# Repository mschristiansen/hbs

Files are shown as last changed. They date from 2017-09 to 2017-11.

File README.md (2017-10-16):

Controller for the Harley Brewing System
========================================

Install Dependencies
--------------------

Requires `avrdude` and `gcc-avr`.

```
$ sudo apt install arduino-mk
```

Initialise git submodules to fetch source code for display and
temperature sensor (installed in `firmware/lib`).

```
$ git submodule init
```

Compile and Upload Firmware
---------------------------

The firmware was tested with Arduino UNO and Arduino Pro Mini. Both of
these boards will auto reset i.e. no need to manually reset before
upload.

Change port and baud rate in `firmware/Makefile` according to
board. The Arduino UNO is generally on port `/dev/ttyACM0` and can
handle speeds up to 115200 baud. The Arduino Pro Mini is generally on
port `/dev/ttyUSB0` and can only handle speeds up to 57600 baud.

```
$ make upload
```

References
----------

- http://www.nongnu.org/avr-libc/user-manual/index.html
- http://playground.arduino.cc/Learning/OneWire

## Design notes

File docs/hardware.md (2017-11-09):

Hardware Setup
==============

Built on Arduino Uno.

DS18B20 Temperature Sensor
--------------------------

- [datasheet](https://cdn.sparkfun.com/datasheets/Sensors/Temp/DS18B20.pdf)
- 5 volt power
- One wire to pin 9 with 4.7k resistor for pull-up
- DS18x20 family

SSD1306 OLED Display
--------------------

- Monochrome
- 128x32 pixels
- 5 volt power
- SDA from display to A4
- SCL from display to A5

Solid-State Relay
-----------------

To control the heater is connected on pin 11, which supports PWM.

MOSFET
------

To control the pump is connected on pin 10. This pin supports PWM, but
that functionality is currently not used.

Buttons
-------

- Button for 'Select' on pin 2 to ground
- Button for 'Next' on pin 3 to ground
- Both pin 2 and 3 support interrupts

Buzzer
------

Buzzer El-Mag PCB 5V, 30 mA attached to pin 8

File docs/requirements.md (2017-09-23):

Requirements
============

1. Must measure the temperature
2. Must display the temperature
3. Must allow setting the temperature
4. Must display the setpoint temperature
5. Must allow switching the pump on and off
6. Must display pump status (on/off)
7. Must make a sound when setpoint temperature is reached

Specifications
--------------

The system will consist of a temperature probe, two buttons, a
display, a buzzer, a solid state relay for the heater and a MOSFET for
the pump.

State
-----

actualTemp
setTemp

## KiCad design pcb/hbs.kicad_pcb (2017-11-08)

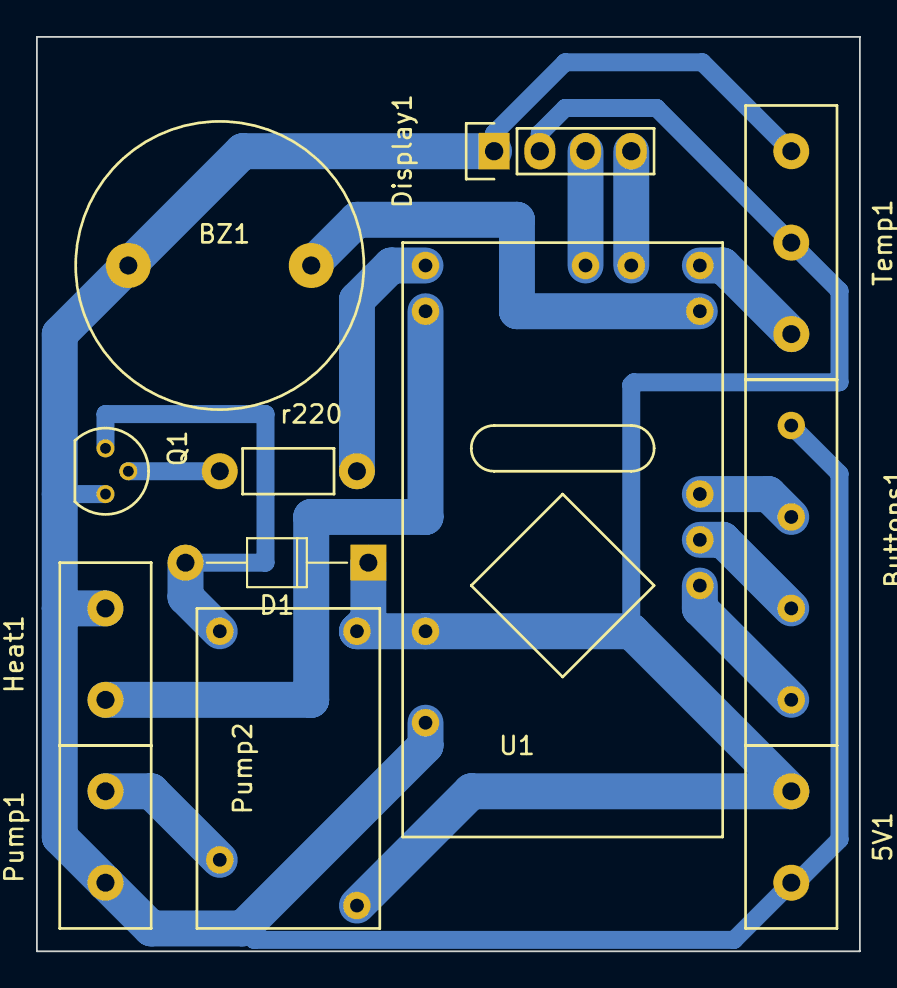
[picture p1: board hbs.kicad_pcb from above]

Board: 2 copper layers, 45.7 x 50.8 mm, 12 parts (0 on the bottom side), 14 nets.

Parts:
5V1: Screw_Terminal_01x02; screw-terminal-2-5.08
BZ1: Buzzer; BUZZER
Buttons1: Conn_01x04; screw-terminal-4-5.08
D1: 1N4148; D_T-1_P10.16mm_Horizontal
Display1: JST Conn; Pin_Header_Straight_1x04
Heat1: Screw_Terminal_01x02; screw-terminal-2-5.08
Pump1: Screw_Terminal_01x02; screw-terminal-2-5.08
Pump2: FINDER-36.11-4301; relay-OJE-SS-105HM
Q1: BC337; TO-92_Molded_Narrow
Temp1: Screw_Terminal_01x03; screw-terminal-3-5.08
U1: RobotDynProMini
r220: R; Resistor_Horizontal_RM7mm

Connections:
GND: 5V1.1, BZ1.1, Buttons1.1, Display1.1, Heat1.1, Pump1.1, Q1.3, Temp1.1, U1.GND
unnamed: BZ1.2, U1.D8
unnamed: Buttons1.2, U1.D4
unnamed: Buttons1.3, U1.D3
unnamed: Buttons1.4, U1.D2
unnamed: D1.2, Pump2.A1, Q1.1
unnamed: Display1.3, U1.A5
unnamed: Display1.4, U1.A4
unnamed: Heat1.2, U1.D11
unnamed: Pump1.2, Pump2.14
unnamed: Q1.2, r220.1
unnamed: Temp1.3, U1.D9
unnamed: U1.D10, r220.2
VCC: 5V1.2, D1.1, Display1.2, Pump2.11, Pump2.A2, Temp1.2, U1.VCC

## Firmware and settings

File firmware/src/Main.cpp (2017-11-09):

#include <Arduino.h>
#include "HBS.h"

void setup();
void loop();

// define the initial state for the system.
struct state initial = {
  0,    // actual temperature
  50,   // setpoint temperature
  OFF,  // Heater
  0,    // Duty-cycle on heater
  OFF,  // Pump
  OFF,  // Buzzer
  HEAT  // Selected menu
};

// Create and initialise the state for the system.
struct state *hbs = &initial;

// Prototypes.
void pumpInit();
void pumpUpdate(int dutyCycle);
void heaterInit();
void heaterUpdate(int dutyCycle);

// the setup function runs once when you press reset or power the board
void setup() {
  Serial.begin(9600);
  initTemp();
  displayInit();
  pumpInit();
  heaterInit();
  initBuzzer();
  initButtons();
}

// the loop function runs over and over again forever
void loop()
{
  // Update state with the current temperature.
  hbs->actualTemp = readTemp();

  readButtons(hbs);
  displayUpdate(*hbs);

  if (hbs->buzzer && hbs->actualTemp > hbs->setTemp)
    soundBuzzer();

  // Pump ON/OFF
  if (hbs->pump)
    pumpUpdate(255);
  else
    pumpUpdate(0);

  // Use PID controller to Set duty-cycle of heater
  hbs->heat = controller(hbs->setTemp - hbs->actualTemp);

  // Heater OFF or PWM
  if (hbs->heater)
    heaterUpdate(hbs->heat);
  else
    heaterUpdate(0);
}

void pumpInit()
{
  pinMode(PUMP_PIN, OUTPUT);
}

// Takes a value from 0-255
void pumpUpdate(int dutyCycle)
{
  analogWrite(PUMP_PIN, dutyCycle);
}

void heaterInit()
{
  pinMode(HEATER_PIN, OUTPUT);
}

// Takes a value from 0-255
void heaterUpdate(int dutyCycle)
{
  analogWrite(HEATER_PIN, dutyCycle);
}

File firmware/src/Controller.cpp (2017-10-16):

#include <Arduino.h>
#include "HBS.h"

unsigned long controllerPrevMillis = 0;
int pwm = 0; // Value for pulse-width-modulation (PWM)

// Slowly lower output from heater as error gets smaller.
int calcpwm(double error)
{
  if (error > 5)
    return 255;
  else if (error > 2)
    return 127;
  else if (error >= 0)
    return 64;
  else if (error < 0)
    return 0;
}


int controller(double error)
{
  unsigned long currentMillis = millis();

  if (currentMillis - controllerPrevMillis >= 1000) {
    // save time of last cycle.
    controllerPrevMillis = currentMillis;

    pwm = calcpwm(error);
  }
  return pwm;
}

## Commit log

2017-08-30 Can display temperature
2017-08-30 Add PID controller module.
2017-09-05 Add button interrupts
2017-09-23 Comment out serial.print commands in temperature module
2017-09-23 Update docs on temperature probe
2017-09-23 Integrated PID controller, but not yet working
2017-09-23 Can switch heater between off and pwm
2017-10-03 Adds hardware
    [hbs_e.fzz]
2017-10-06 Move firmware source code to firmware directory
    [hbs_e.fzz]
2017-10-07 Add datasheet for temperature sensor
2017-10-10 Refactor temperature and buttons. Add buzzer to display.
    [Buttons.cpp, Main.cpp, Temperature.cpp]
2017-10-16 Use simpler control algorithm for temperature control
2017-11-07 Add KiCAD files for RobotDyn PCB
    [hbs.kicad_pcb, hbs.sch]
2017-11-08 Change relay footprint and cosmetic changes to schematic
    [hbs.kicad_pcb, hbs.sch]
2017-11-09 Change firmware to support more temperature sensors
2017-11-09 Add pull-up resistor for temperature sensor to schematic
    [hbs.sch]
